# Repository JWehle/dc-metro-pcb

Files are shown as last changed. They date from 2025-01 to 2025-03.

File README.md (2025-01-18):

This repository holds the files used to design and manufacture the DCTransistor boards themselves.

[DCTransistor_updated.svg](DCTransistor_updated.svg) is an InkScape project file containing the PCB artwork (i.e. map design). The map is the inkscape file used on the most recent (Bidirectional) version of the boards.

The original Inkscape file used to create the first production DCTransistor board run is still available at [DCTransistor_orig.svg](DCTransistor_orig.svg)

`DCTransistor_*_BOM.xlsx` files are bills of materials needed to specify the board parts when ordering from JLCPCB.

The remaining files in `DCTransistor_*_Kicad_Modules.zip` are modified Kicad modules with modified PCB footprints from the default parts' Kicad libraries. Specifically, the footprints were modified to remove nearly all material that would normally be printed on a PCB and shrunk the silkscreen used to identify the orientation / polarity of the LEDs so that they would only be printed under the placed LEDs. 

The best way to get started modifying the projectin KiCad is to download all the Kicad files for a project (everything except the .svg) into a single folder, with the Kicad_Modules zip extracted as a sub-folder, and load the folder as a new KiCad project. The Kicad_Modules extracted sub-folder will need to be added to Kicad as a new source of footprints to use with the project.

Turning DCTransistor.svg into a KiCad modules requires using the [svg2shenzhen module](https://github.com/badgeek/svg2shenzhen). This [DEFCON talk from TwinkleTwinkie](https://www.youtube.com/watch?v=Sbkvza8cKQE) was my starting point learning how to make PCB art and turn it into a functioning board.

All contents of this folder are [licensed](LICENSE.md) under a Creative Commons Attribution-NonCommercial-ShareAlike 4.0 International Public License.

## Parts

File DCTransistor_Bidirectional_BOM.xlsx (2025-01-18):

Comment | Designator | Footprint | LCSC Part Number | Basic? | Doable |  | Old Part Numbers
MMBT3904 | Q1,Q0 | SOT-23 | C20526 | Y | Y |  | C20526
1N5819WS | D0 | SOD-323 | C191023 | Y | Y |  | C191023
SN74LVC1T45DBV | U3 | SOT-23-6 | C7843 | Y | Y |  | C7843
CH340C | U0 | SOIC-16_3.9x9.9mm_P1.27mm | C84681 | N | N |  | C84681
ESP-12F | U2 | ESP-12E | C82891 | N | N |  | C82891
AMS1117-3.3 | U1 | SOT-223-3_TabPin2 | C6186 | Y | Y |  | C351784
SW_SPST | SW0 | SW_DIP_SPSTx01_Slide_6.7x4.1mm_W6.73mm_P2.54mm_LowProfile_JPin | C54948 | N | N |  | C54948
300 | R8 | R_0402_1005Metric | C25102 | Y | Y |  | C138010
12k | R4,R5 | R_0402_1005Metric | C25752 | Y | Y |  | C144798
470 | R1,R2 | R_0402_1005Metric | C25117 | Y | Y | 0402 | C114433
10k | R6,R7,R9 | R_0402_1005Metric | C25744 | Y | Y | 0402 | C17414
5.1kR | R3,R0 | R_0402_1005Metric | C25905 | Y | Y | 0402 | C14677
USB_C_Receptacle | J0 | USB_C_Receptacle_HRO_TYPE-C-31-M-12 | C165948 | N | N |  | C165948
WS2812B_2.0mm_2.0mm | D2,D3,D4,D5,D6,D7,D8,D9,D10,D11,D12,D13,D14,D15,D16,D17,D18,D19,D20,D21,D22,D23,D24,D25,D26,D27,D28,D29,D30,D31,D32,D33,D34,D35,D36,D37,D38,D39,D40,D41,D42,D43,D44,D45,D46,D47,D48,D49,D50,D51,D52,D53,D54,D55,D56,D57,D58,D59,D60,D61,D62,D63,D64,D65,D66,D67,D68,D69,D70,D71,D72,D73,D74,D75,D76,D77,D78,D79,D80,D81,D82,D83,D84,D85,D86,D87,D88,D89,D90,D91,D92,D93,D94,D95,D96,D97,D98,D99,D100,D101,D102,D103,D104,D105,D106,D107,D108,D109,D110,D111,D112,D113,D114,D115,D116,D117,D118,D119,D120,D121,D122,D123,D124,D125,D126,D127,D128,D129,D130,D131,D132,D133,D134,D135,D136,D137,D138,D139,D140,D141,D142,D143,D144,D145,D146,D147,D148,D149,D150,D151,D152,D153,D154,D155,D156,D157,D158,D159,D160,D161,D162,D163,D164,D165,D166,D167,D168,D169,D170,D171,D172,D173,D174,D175,D176,D177,D178,D179,D180,D181,D182,D183,D184,D185,D186,D187,D188,D189,D190,D191,D192,D193,D194,D195,D196,D197,D198,D199,D200,D201,D202,D203,D204,D205,D206,D207,D208 | LED_2020 | C5349955 | N | N | To allow economic assembly | C2761795
100nf | C0,C2 | C_0603_1608Metric | C14663 | Y | Y | 0603 | C88219
10uF | C1,C3,C4,C5,C6,C7,C8,C9,C10,C11,C12,C13,C14,C15,C16,C17,C18,C19,C20,C21,C22,C23,C24,C25,C26,C27,C28,C29,C30,C31,C32,C33,C34,C35,C36,C37,C38,C39,C40,C41,C42,C43 | C_0402_1005Metric | C15525 | Y | Y | 0402 | C466780

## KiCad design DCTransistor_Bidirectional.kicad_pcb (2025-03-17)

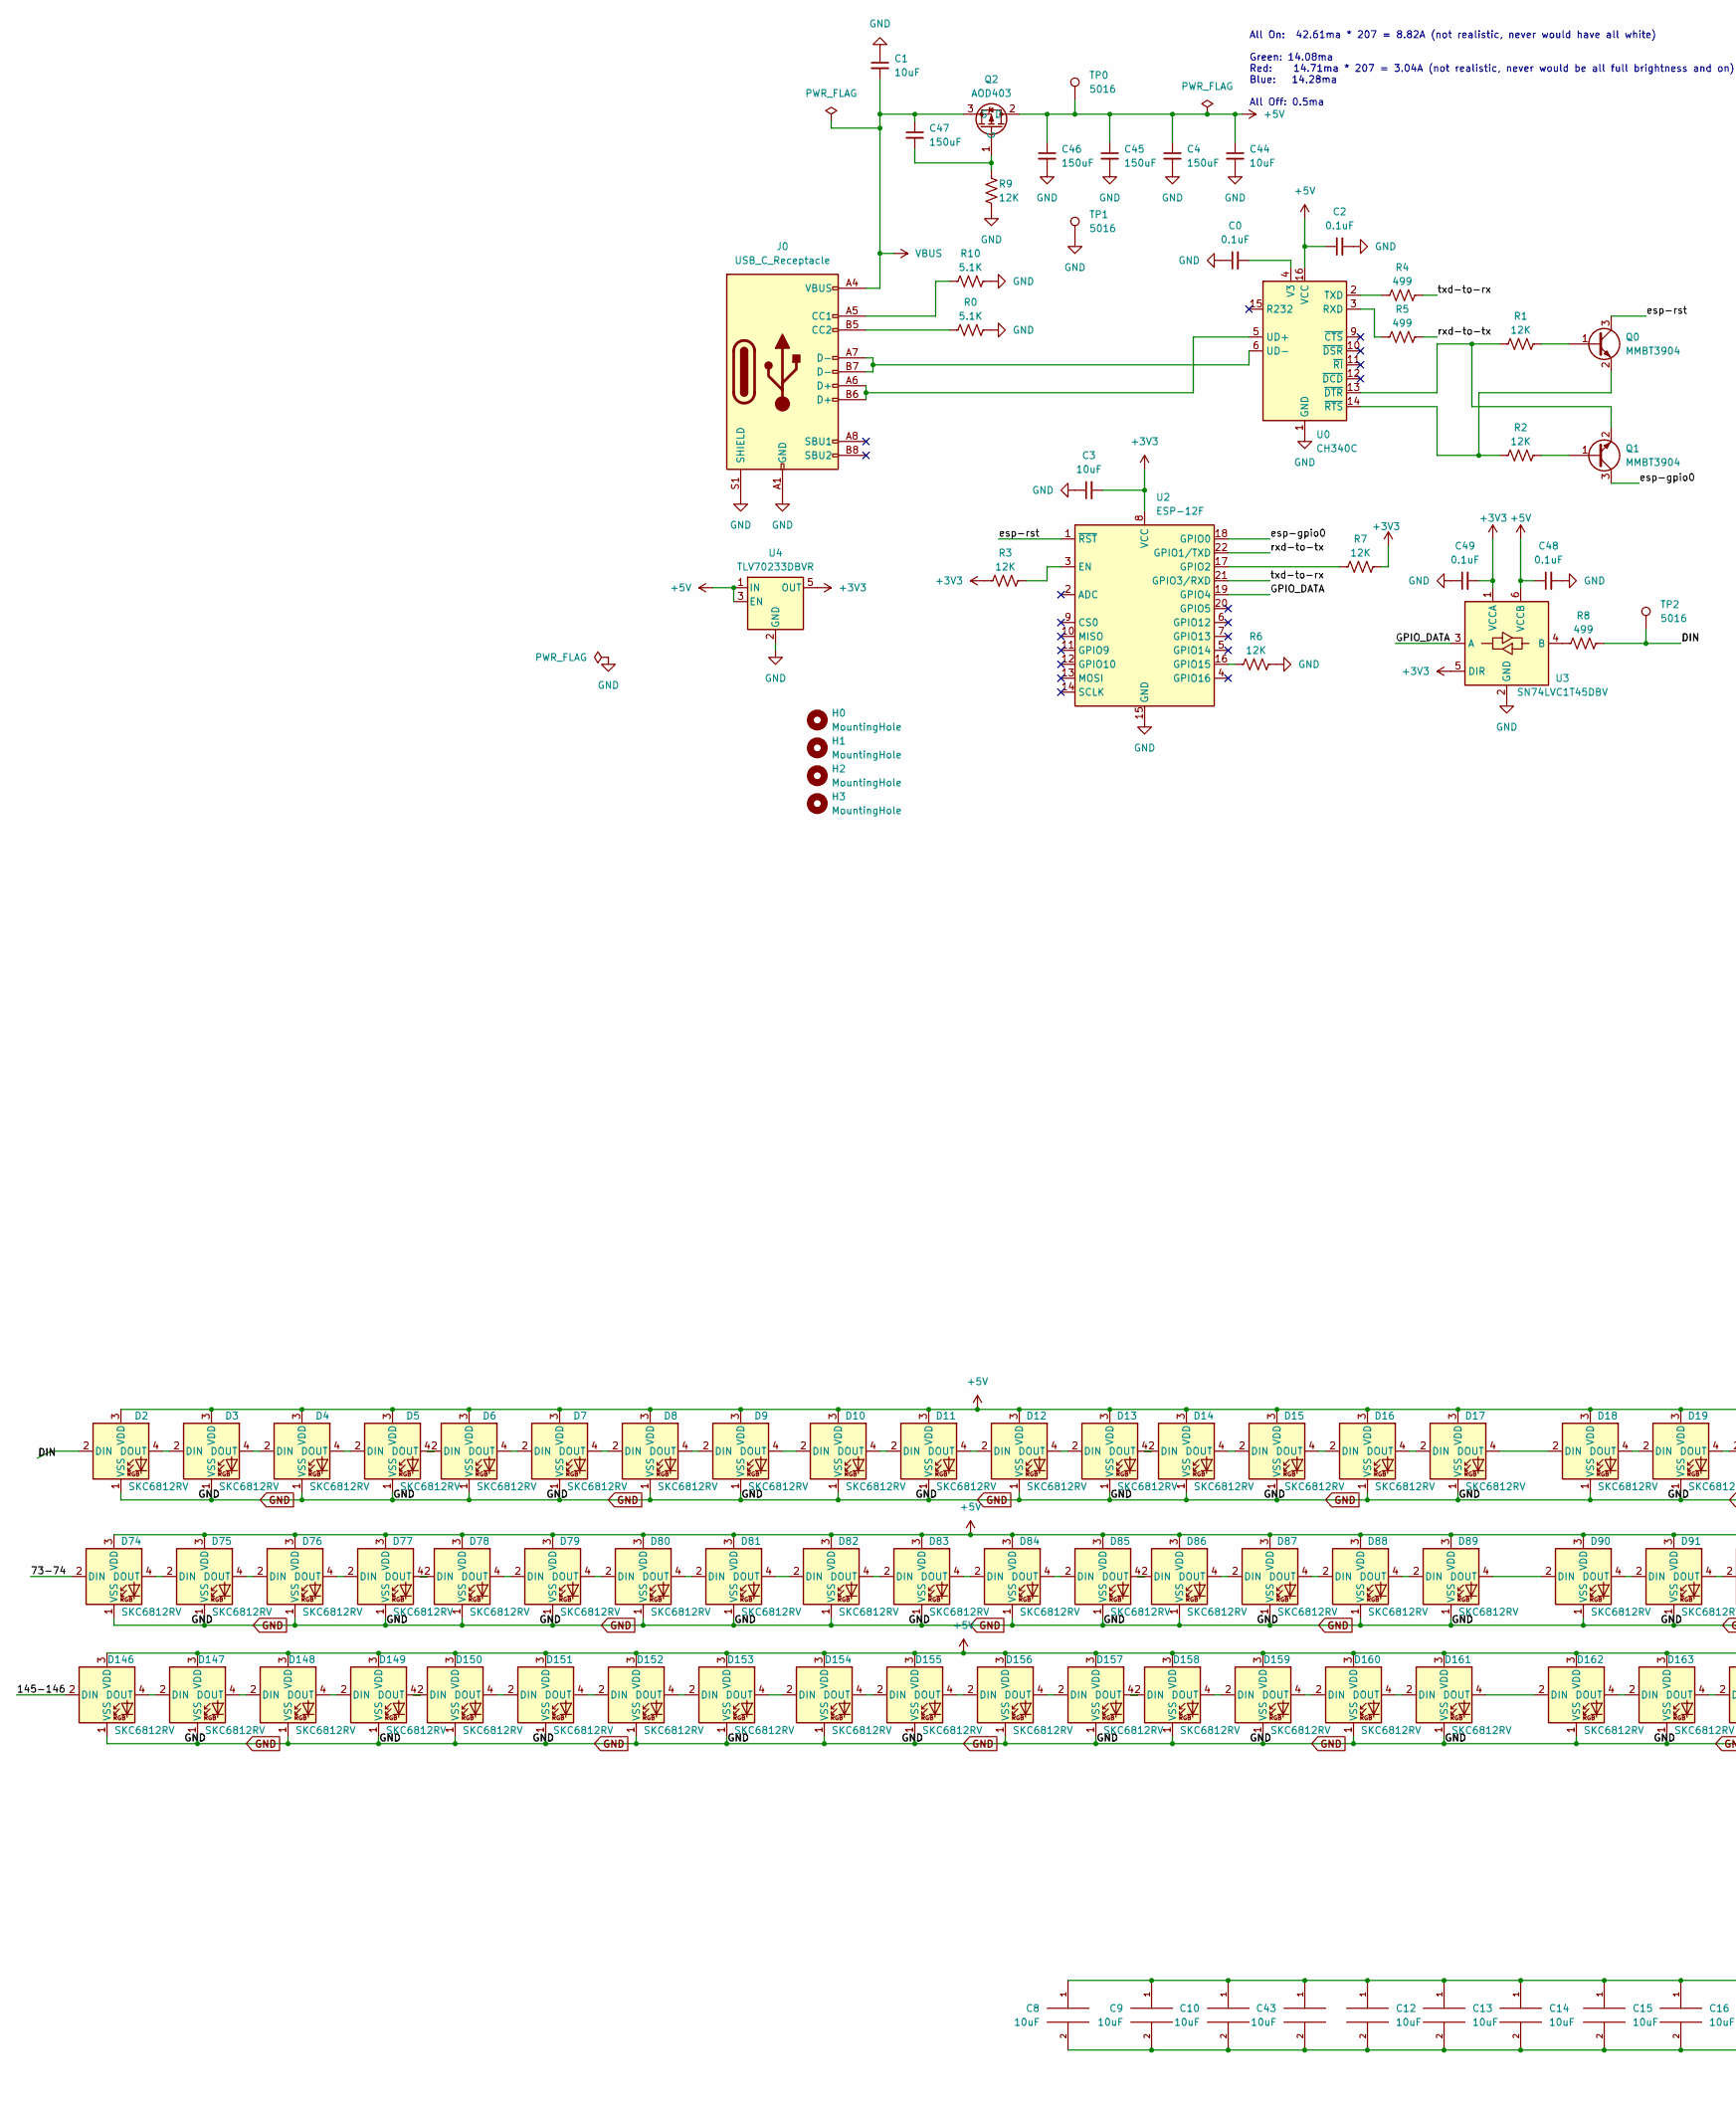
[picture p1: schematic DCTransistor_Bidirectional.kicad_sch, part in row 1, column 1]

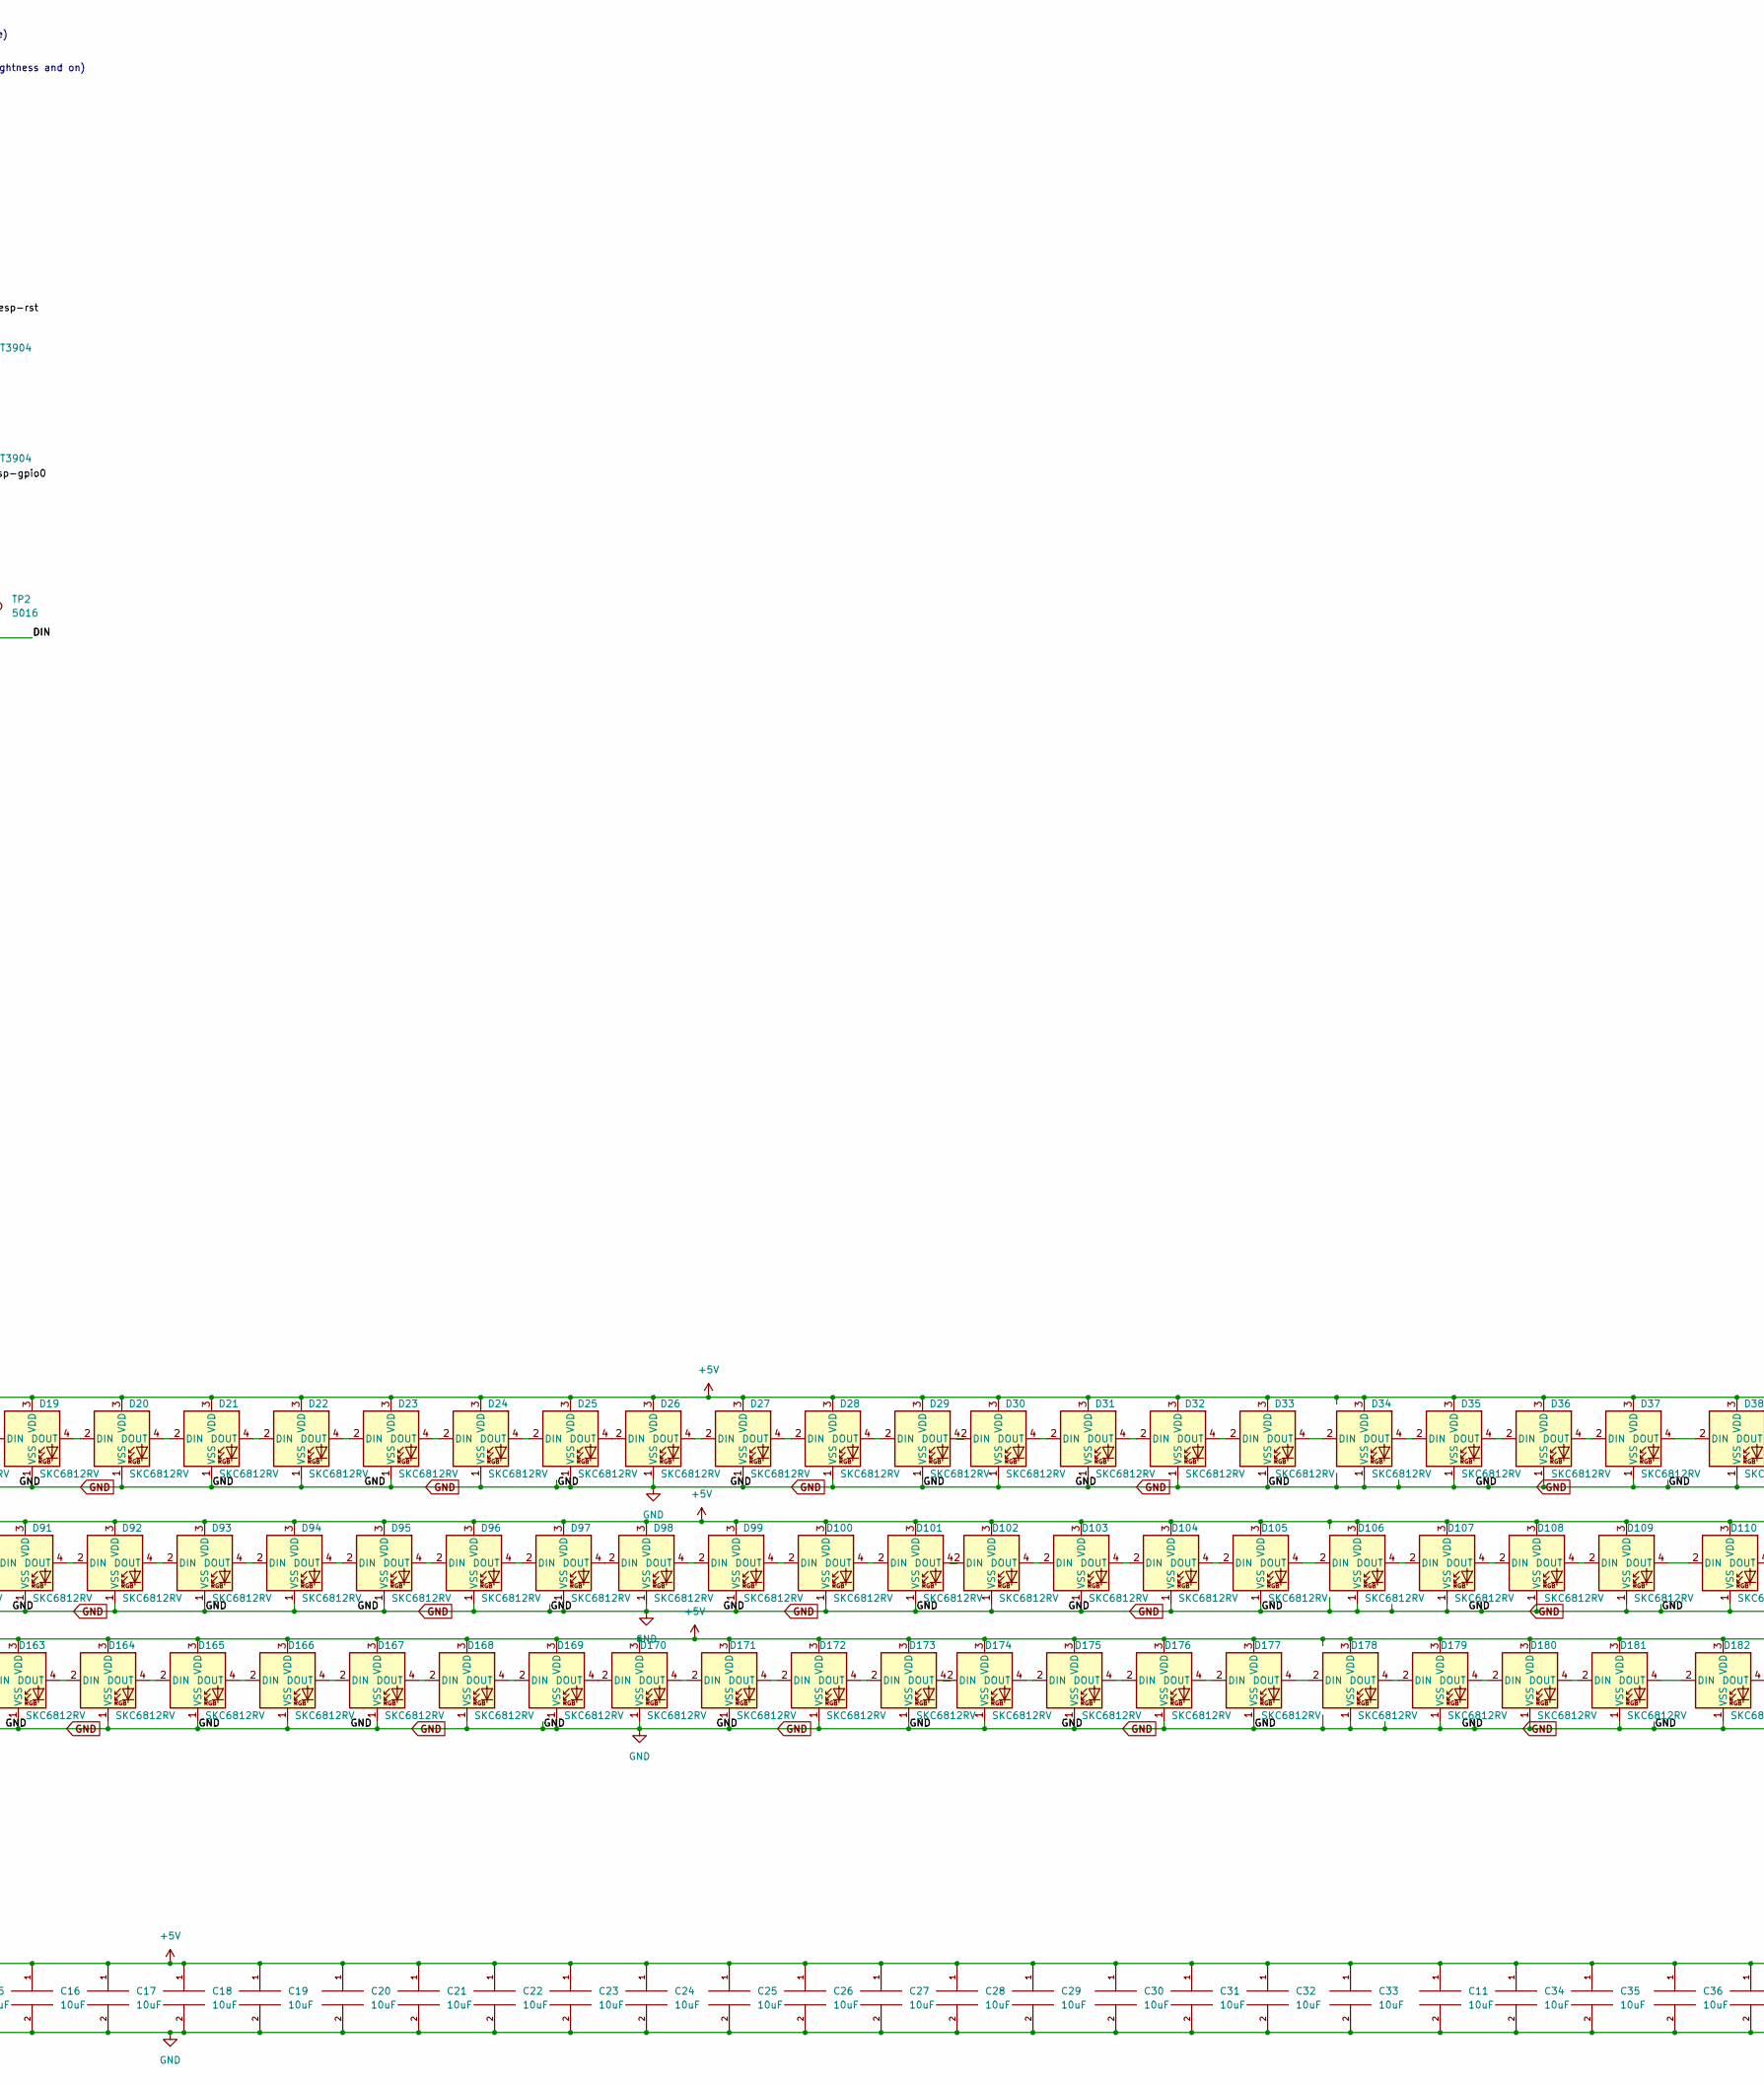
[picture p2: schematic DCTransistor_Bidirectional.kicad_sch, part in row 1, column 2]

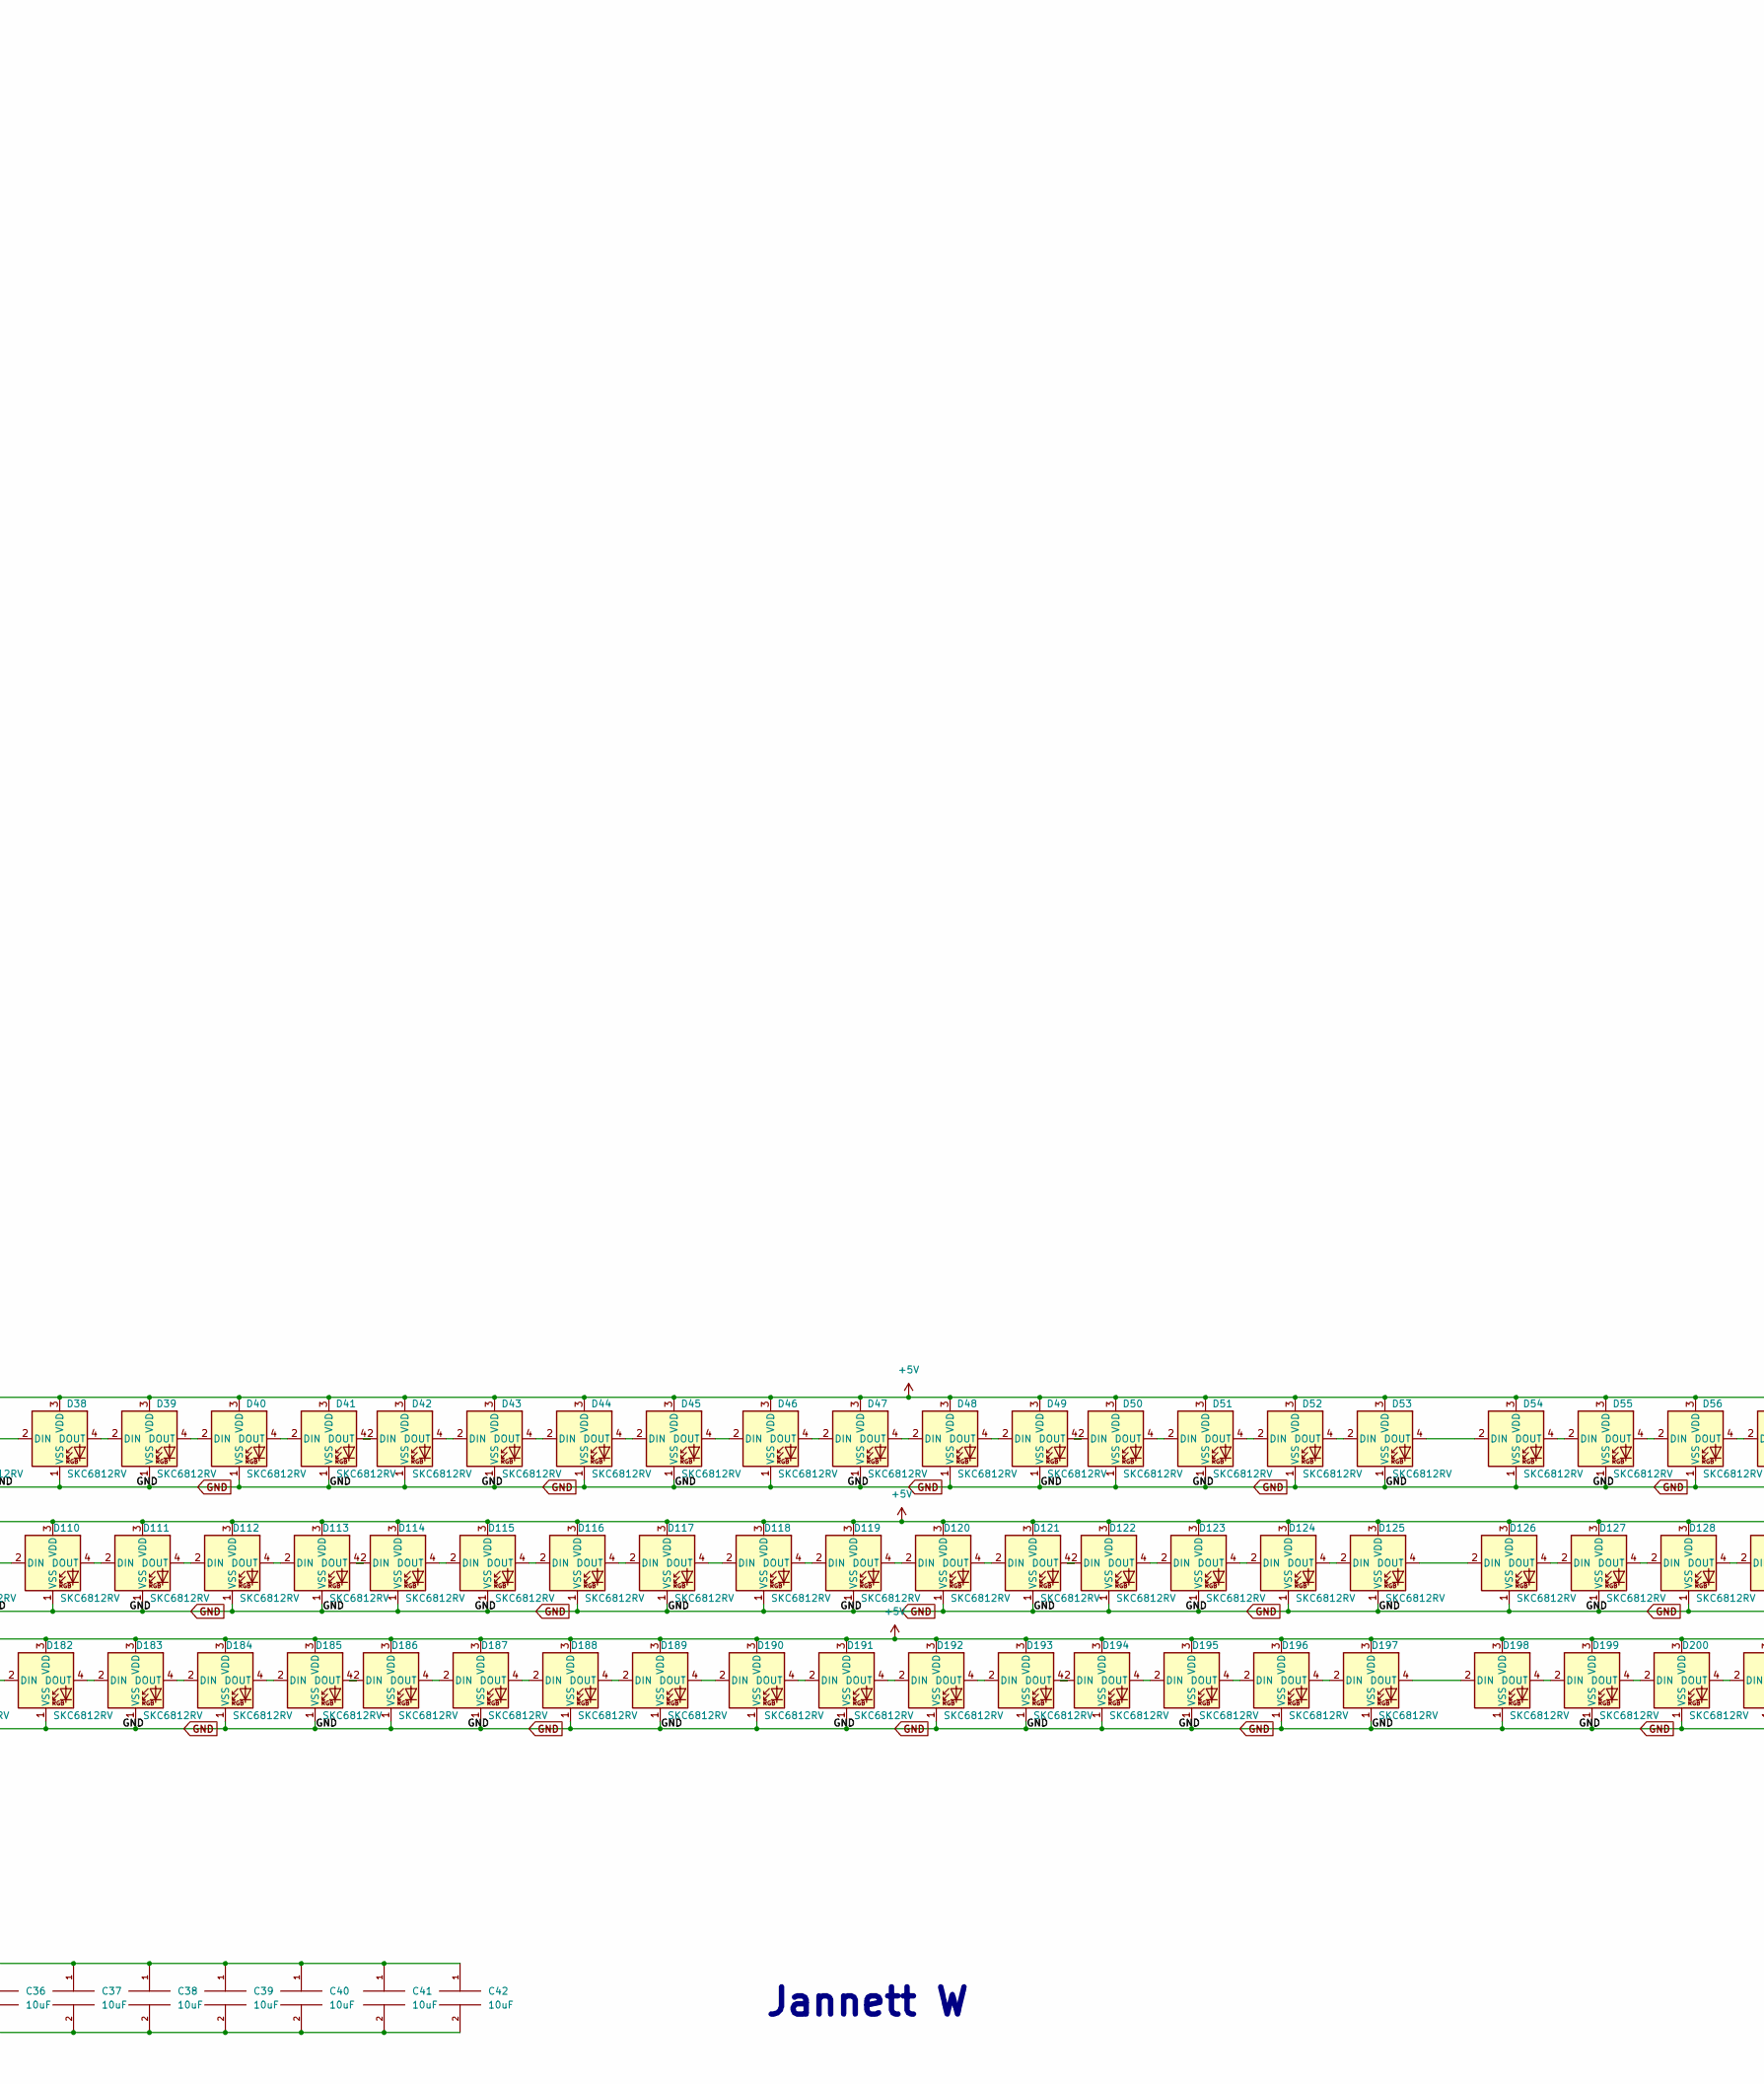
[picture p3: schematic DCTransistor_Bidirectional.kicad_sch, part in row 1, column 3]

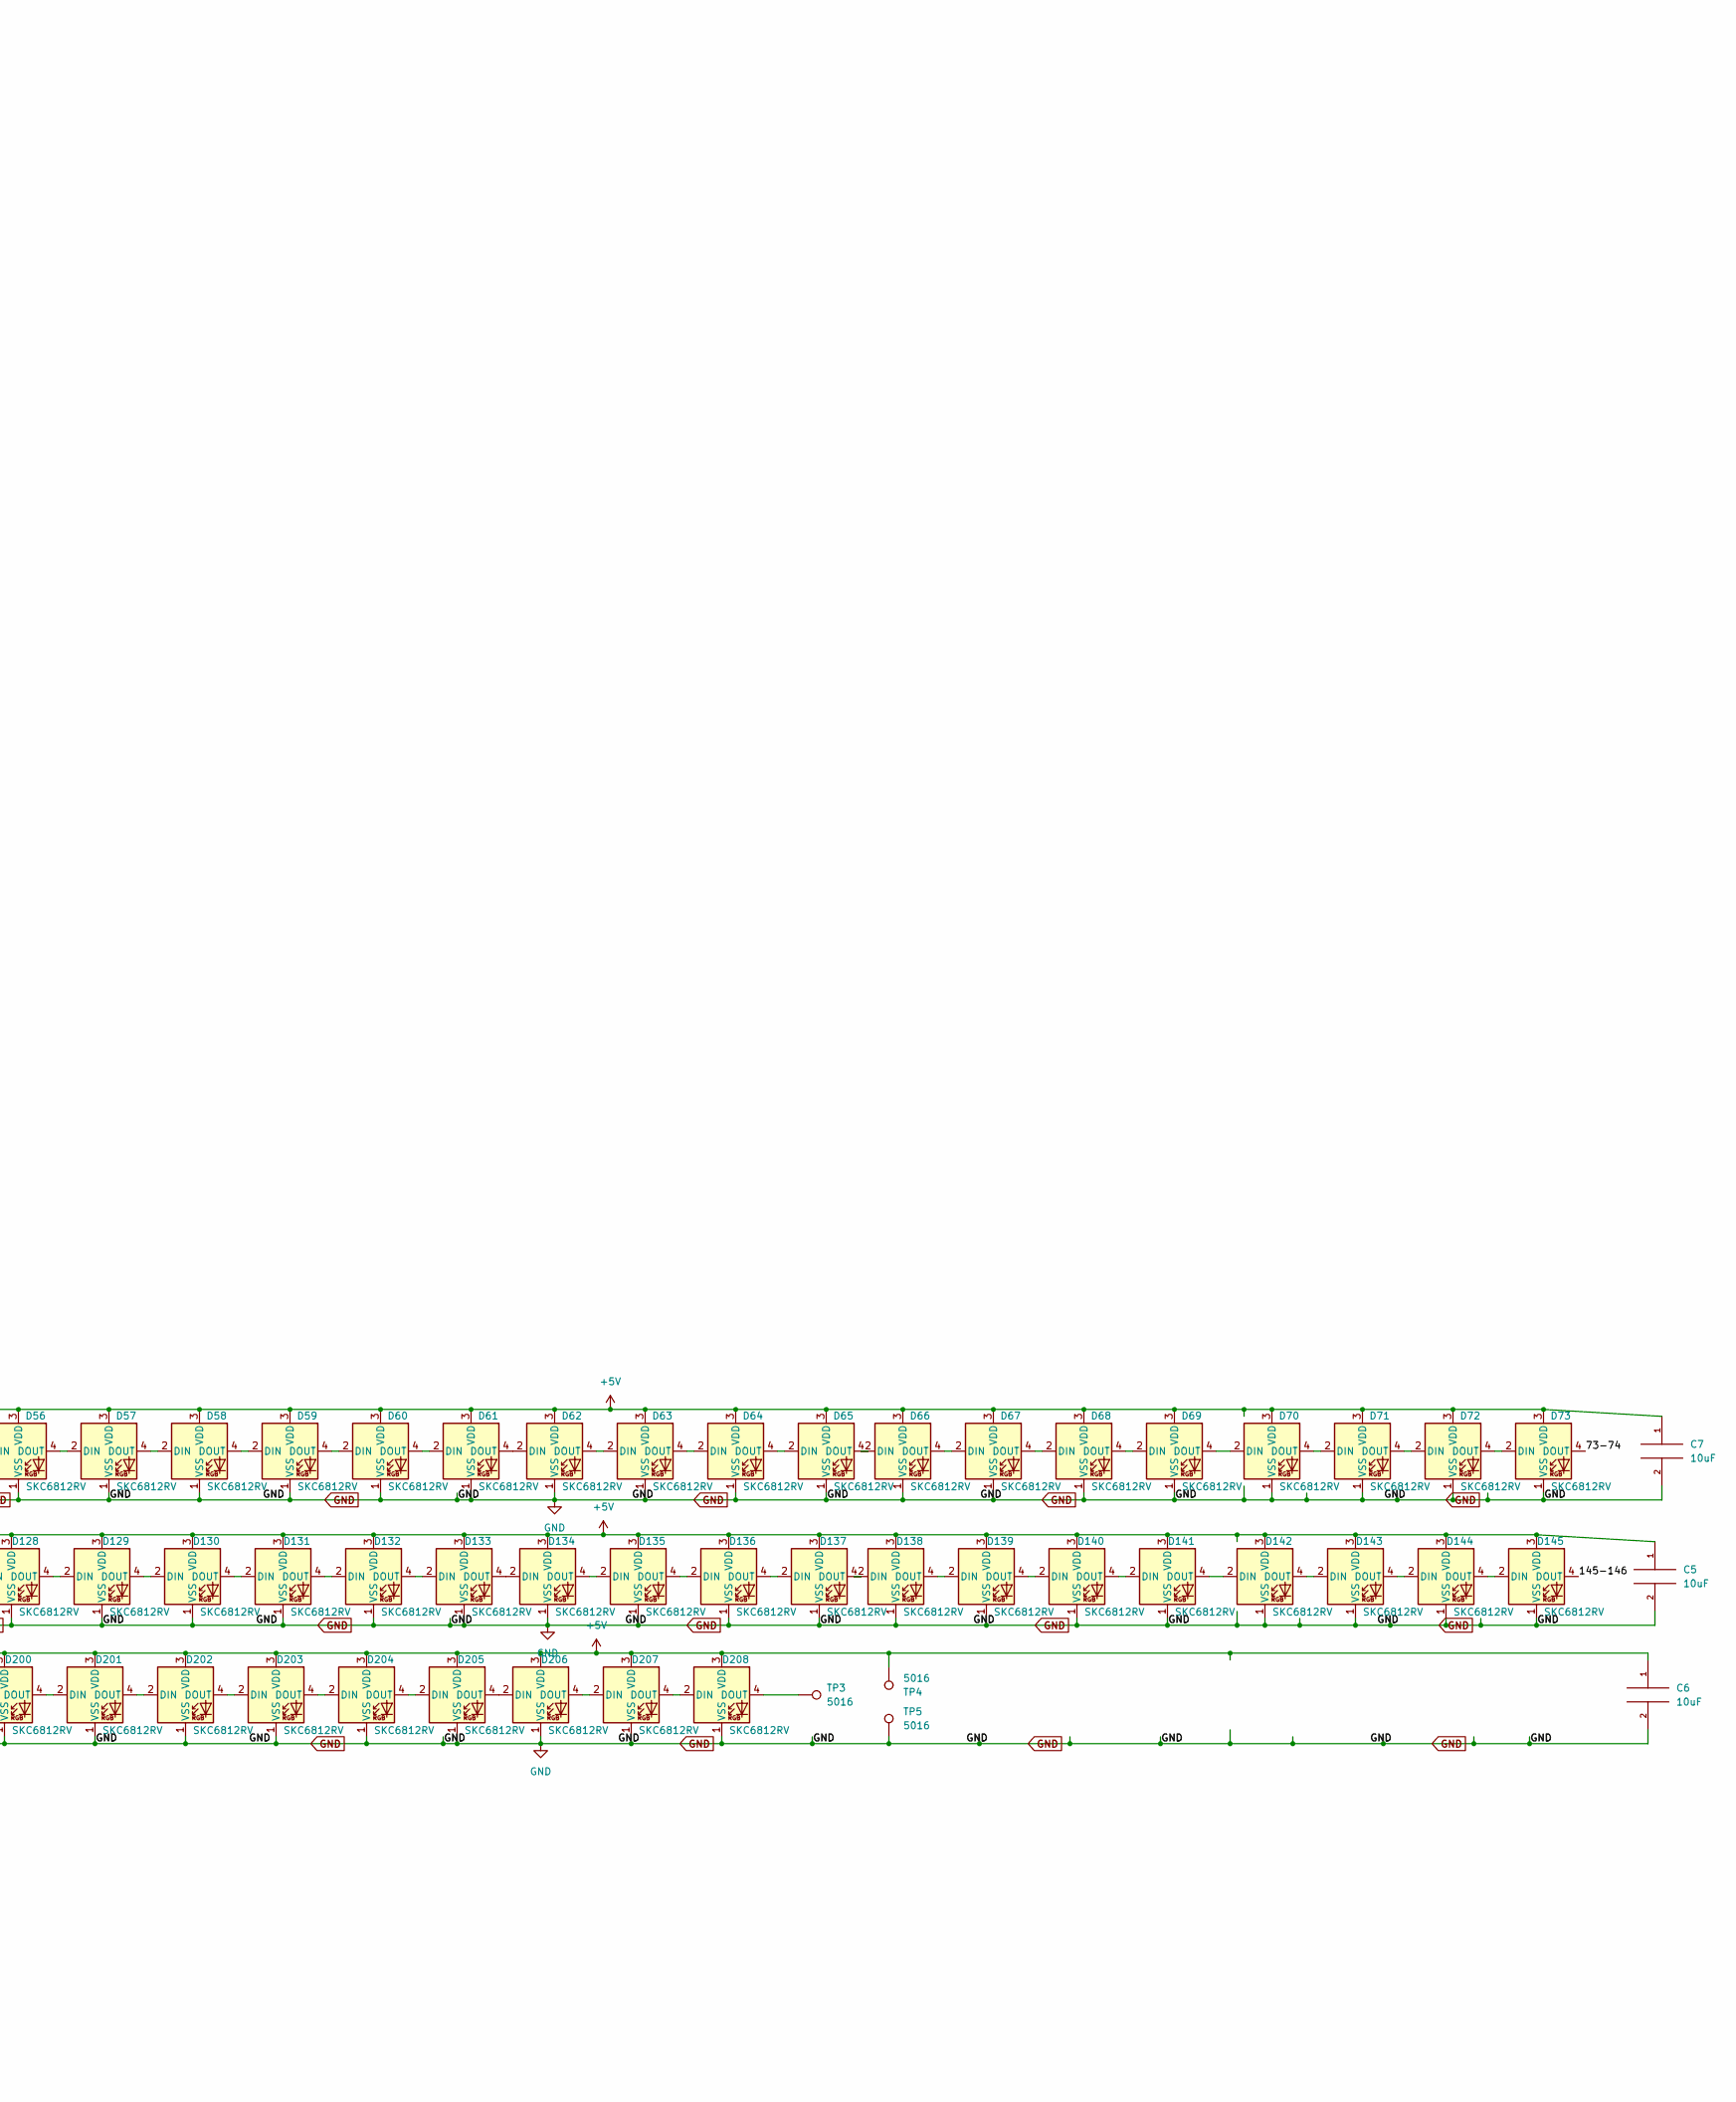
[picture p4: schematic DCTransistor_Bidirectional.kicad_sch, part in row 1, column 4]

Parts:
C0, C2, C48, C49: 0.1uF; C_0603_1608Metric
C1, C3, C5, C6, C7, C8, C9, C10, C11, C12, C13, C14, C15, C16, C17, C18, C19, C20, C21, C22, C23, C24, C25, C26, C27, C28, C29, C30, C31, C32, C33, C34, C35, C36, C37, C38, C39, C40, C41, C42, C43, C44: 10uF; C_0603_1608Metric
C4, C45, C46, C47: 150uF; CP_EIA-7343-43_Kemet-X_Pad2.25x2.55mm_HandSolder
D2, D3, D4, D5, D6, D7, D8, D9, D10, D11, D12, D13, D14, D15, D16, D17, D18, D19, D20, D21, D22, D23, D24, D25, D26, D27, D28, D29, D30, D31, D32, D33, D34, D35, D36, D37, D38, D39, D40, D41, D42, D43, D44, D45, D46, D47, D48, D49, D50, D51, D52, D53, D54, D55, D56, D57, D58, D59, D60, D61, D62, D63, D64, D65, D66, D67, D68, D69, D70, D71, D72, D73, D74, D75, D76, D77, D78, D79, D80, D81, D82, D83, D84, D85, D86, D87, D88, D89, D90, D91, D92, D93, D94, D95, D96, D97, D98, D99, D100, D101, D102, D103, D104, D105, D106, D107, D108, D109, D110, D111, D112, D113, D114, D115, D116, D117, D118, D119, D120, D121, D122, D123, D124, D125, D126, D127, D128, D129, D130, D131, D132, D133, D134, D135, D136, D137, D138, D139, D140, D141, D142, D143, D144, D145, D146, D147, D148, D149, D150, D151, D152, D153, D154, D155, D156, D157, D158, D159, D160, D161, D162, D163, D164, D165, D166, D167, D168, D169, D170, D171, D172, D173, D174, D175, D176, D177, D178, D179, D180, D181, D182, D183, D184, D185, D186, D187, D188, D189, D190, D191, D192, D193, D194, D195, D196, D197, D198, D199, D200, D201, D202, D203, D204, D205, D206, D207, D208: SKC6812RV; LED_SK6812_PLCC4_5.0x5.0mm_P3.2mm_no_silk
H0, H1, H2, H3: MountingHole; MountingHole_6.4mm_M6
J0: USB_C_Receptacle; USB_C_Receptacle_GSB1C4621DS2HR
Q0, Q1: MMBT3904; SOT-23-3
Q2: AOD403; TO-252-2
R0, R10: 5.1K; R_0603_1608Metric
R1, R2, R3, R6, R7, R9: 12K; R_0603_1608Metric
R4, R5, R8: 499; R_0603_1608Metric
TP0, TP1, TP2, TP3, TP4, TP5: 5016; TestPoint_Keystone_5016_Compact
U0: CH340C; SOIC-16_3.9x9.9mm_P1.27mm
U2: ESP-12F; ESP-12E
U3: SN74LVC1T45DBV; SOT-23-6_Handsoldering
U4: TLV70233DBVR; SOT-23-5

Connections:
+3V3: C3.2, C49.2, R3.1, R7.2, U2.8 (VCC), U3.1 (VCCA), U3.5 (DIR), U4.5 (OUT)
+5V: C2.1, C4.1, C5.1, C6.1, C7.1, C8.1, C9.1, C10.1, C11.1, C12.1, C13.1, C14.1, C15.1, C16.1, C17.1, C18.1, C19.1, C20.1, C21.1, C22.1, C23.1, C24.1, C25.1, C26.1, C27.1, C28.1, C29.1, C30.1, C31.1, C32.1, C33.1, C34.1, C35.1, C36.1, C37.1, C38.1, C39.1, C40.1, C41.1, C42.1, C43.1, C44.1, C45.1, C46.1, C48.1, D2.3 (VDD), D3.3 (VDD), D4.3 (VDD), D5.3 (VDD), D6.3 (VDD), D7.3 (VDD), D8.3 (VDD), D9.3 (VDD), D10.3 (VDD), D11.3 (VDD), D12.3 (VDD), D13.3 (VDD), D14.3 (VDD), D15.3 (VDD), D16.3 (VDD), D17.3 (VDD), D18.3 (VDD), D19.3 (VDD), D20.3 (VDD), D21.3 (VDD), D22.3 (VDD), D23.3 (VDD), D24.3 (VDD), D25.3 (VDD), D26.3 (VDD), D27.3 (VDD), D28.3 (VDD), D29.3 (VDD), D30.3 (VDD), D31.3 (VDD), D32.3 (VDD), D33.3 (VDD), D34.3 (VDD), D35.3 (VDD), D36.3 (VDD), D37.3 (VDD), D38.3 (VDD), D39.3 (VDD), D40.3 (VDD), D41.3 (VDD), D42.3 (VDD), D43.3 (VDD), D44.3 (VDD), D45.3 (VDD), D46.3 (VDD), D47.3 (VDD), D48.3 (VDD), D49.3 (VDD), D50.3 (VDD), D51.3 (VDD), D52.3 (VDD), D53.3 (VDD), D54.3 (VDD), D55.3 (VDD), D56.3 (VDD), D57.3 (VDD), D58.3 (VDD), D59.3 (VDD), D60.3 (VDD), D61.3 (VDD)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
/73-74: D73.4 (DOUT), D74.2 (DIN)
/145-146: D145.4 (DOUT), D146.2 (DIN)
/DIN: D2.2 (DIN), R8.2, TP2.1
/GPIO_DATA: U2.19 (GPIO4), U3.3 (A)
/esp-gpio0: Q1.3 (C), U2.18 (GPIO0)
/esp-rst: Q0.3 (C), U2.1 (~RST)
/rxd-to-tx: R5.2, U2.22 (GPIO1/TXD)
/txd-to-rx: R4.2, U2.21 (GPIO3/RXD)
GND: C0.1, C1.1, C2.2, C3.1, C4.2, C5.2, C6.2, C7.2, C8.2, C9.2, C10.2, C11.2, C12.2, C13.2, C14.2, C15.2, C16.2, C17.2, C18.2, C19.2, C20.2, C21.2, C22.2, C23.2, C24.2, C25.2, C26.2, C27.2, C28.2, C29.2, C30.2, C31.2, C32.2, C33.2, C34.2, C35.2, C36.2, C37.2, C38.2, C39.2, C40.2, C41.2, C42.2, C43.2, C44.2, C45.2, C46.2, C48.2, C49.1, D2.1 (VSS), D3.1 (VSS), D4.1 (VSS), D5.1 (VSS), D6.1 (VSS), D7.1 (VSS), D8.1 (VSS), D9.1 (VSS), D10.1 (VSS), D11.1 (VSS), D12.1 (VSS), D13.1 (VSS), D14.1 (VSS), D15.1 (VSS), D16.1 (VSS), D17.1 (VSS), D18.1 (VSS), D19.1 (VSS), D20.1 (VSS), D21.1 (VSS), D22.1 (VSS), D23.1 (VSS), D24.1 (VSS), D25.1 (VSS), D26.1 (VSS), D27.1 (VSS), D28.1 (VSS), D29.1 (VSS), D30.1 (VSS), D31.1 (VSS), D32.1 (VSS), D33.1 (VSS), D34.1 (VSS), D35.1 (VSS), D36.1 (VSS), D37.1 (VSS), D38.1 (VSS), D39.1 (VSS), D40.1 (VSS), D41.1 (VSS), D42.1 (VSS), D43.1 (VSS), D44.1 (VSS), D45.1 (VSS), D46.1 (VSS), D47.1 (VSS), D48.1 (VSS), D49.1 (VSS), D50.1 (VSS), D51.1 (VSS), D52.1 (VSS), D53.1 (VSS), D54.1 (VSS), D55.1 (VSS), D56.1 (VSS), D57.1 (VSS)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
unnamed: D2.4 (DOUT), D3.2 (DIN)
unnamed: D3.4 (DOUT), D4.2 (DIN)
unnamed: D4.4 (DOUT), D5.2 (DIN)
unnamed: D5.4 (DOUT), D6.2 (DIN)
unnamed: D6.4 (DOUT), D7.2 (DIN)
unnamed: D7.4 (DOUT), D8.2 (DIN)
unnamed: D8.4 (DOUT), D9.2 (DIN)
unnamed: D9.4 (DOUT), D10.2 (DIN)
unnamed: D10.4 (DOUT), D11.2 (DIN)
unnamed: D11.4 (DOUT), D12.2 (DIN)
unnamed: D12.4 (DOUT), D13.2 (DIN)
unnamed: D13.4 (DOUT), D14.2 (DIN)
unnamed: D14.4 (DOUT), D15.2 (DIN)
unnamed: D15.4 (DOUT), D16.2 (DIN)
unnamed: D16.4 (DOUT), D17.2 (DIN)
unnamed: D17.4 (DOUT), D18.2 (DIN)
unnamed: D18.4 (DOUT), D19.2 (DIN)
unnamed: D19.4 (DOUT), D20.2 (DIN)
unnamed: D20.4 (DOUT), D21.2 (DIN)
unnamed: D21.4 (DOUT), D22.2 (DIN)
unnamed: D22.4 (DOUT), D23.2 (DIN)
unnamed: D23.4 (DOUT), D24.2 (DIN)
unnamed: D24.4 (DOUT), D25.2 (DIN)
unnamed: D25.4 (DOUT), D26.2 (DIN)
unnamed: D26.4 (DOUT), D27.2 (DIN)
unnamed: D27.4 (DOUT), D28.2 (DIN)
unnamed: D28.4 (DOUT), D29.2 (DIN)
unnamed: D29.4 (DOUT), D30.2 (DIN)
unnamed: D30.4 (DOUT), D31.2 (DIN)
unnamed: D31.4 (DOUT), D32.2 (DIN)
unnamed: D32.4 (DOUT), D33.2 (DIN)
unnamed: D33.4 (DOUT), D34.2 (DIN)
unnamed: D34.4 (DOUT), D35.2 (DIN)
unnamed: D35.4 (DOUT), D36.2 (DIN)
unnamed: D36.4 (DOUT), D37.2 (DIN)
unnamed: D37.4 (DOUT), D38.2 (DIN)
unnamed: D38.4 (DOUT), D39.2 (DIN)
unnamed: D39.4 (DOUT), D40.2 (DIN)
unnamed: D40.4 (DOUT), D41.2 (DIN)
unnamed: D41.4 (DOUT), D42.2 (DIN)
unnamed: D42.4 (DOUT), D43.2 (DIN)
unnamed: D43.4 (DOUT), D44.2 (DIN)
unnamed: D44.4 (DOUT), D45.2 (DIN)
unnamed: D45.4 (DOUT), D46.2 (DIN)
unnamed: D46.4 (DOUT), D47.2 (DIN)
unnamed: D47.4 (DOUT), D48.2 (DIN)
unnamed: D48.4 (DOUT), D49.2 (DIN)
unnamed: D49.4 (DOUT), D50.2 (DIN)
unnamed: D50.4 (DOUT), D51.2 (DIN)
unnamed: D51.4 (DOUT), D52.2 (DIN)
unnamed: D52.4 (DOUT), D53.2 (DIN)
unnamed: D53.4 (DOUT), D54.2 (DIN)
unnamed: D54.4 (DOUT), D55.2 (DIN)
unnamed: D55.4 (DOUT), D56.2 (DIN)
unnamed: D56.4 (DOUT), D57.2 (DIN)
unnamed: D57.4 (DOUT), D58.2 (DIN)
unnamed: D58.4 (DOUT), D59.2 (DIN)
unnamed: D59.4 (DOUT), D60.2 (DIN)
unnamed: D60.4 (DOUT), D61.2 (DIN)
unnamed: D61.4 (DOUT), D62.2 (DIN)
unnamed: D62.4 (DOUT), D63.2 (DIN)
unnamed: D63.4 (DOUT), D64.2 (DIN)
unnamed: D64.4 (DOUT), D65.2 (DIN)
unnamed: D65.4 (DOUT), D66.2 (DIN)
unnamed: D66.4 (DOUT), D67.2 (DIN)
unnamed: D67.4 (DOUT), D68.2 (DIN)
unnamed: D68.4 (DOUT), D69.2 (DIN)
unnamed: D69.4 (DOUT), D70.2 (DIN)
unnamed: D70.4 (DOUT), D71.2 (DIN)
unnamed: D71.4 (DOUT), D72.2 (DIN)
unnamed: D72.4 (DOUT), D73.2 (DIN)
unnamed: D74.4 (DOUT), D75.2 (DIN)
unnamed: D75.4 (DOUT), D76.2 (DIN)
unnamed: D76.4 (DOUT), D77.2 (DIN)
unnamed: D77.4 (DOUT), D78.2 (DIN)
unnamed: D78.4 (DOUT), D79.2 (DIN)
unnamed: D79.4 (DOUT), D80.2 (DIN)
unnamed: D80.4 (DOUT), D81.2 (DIN)
unnamed: D81.4 (DOUT), D82.2 (DIN)
unnamed: D82.4 (DOUT), D83.2 (DIN)
unnamed: D83.4 (DOUT), D84.2 (DIN)
unnamed: D84.4 (DOUT), D85.2 (DIN)
unnamed: D85.4 (DOUT), D86.2 (DIN)
unnamed: D86.4 (DOUT), D87.2 (DIN)
unnamed: D87.4 (DOUT), D88.2 (DIN)
unnamed: D88.4 (DOUT), D89.2 (DIN)
unnamed: D89.4 (DOUT), D90.2 (DIN)
unnamed: D90.4 (DOUT), D91.2 (DIN)
unnamed: D91.4 (DOUT), D92.2 (DIN)
unnamed: D92.4 (DOUT), D93.2 (DIN)
unnamed: D93.4 (DOUT), D94.2 (DIN)
unnamed: D94.4 (DOUT), D95.2 (DIN)
unnamed: D95.4 (DOUT), D96.2 (DIN)
unnamed: D96.4 (DOUT), D97.2 (DIN)
unnamed: D97.4 (DOUT), D98.2 (DIN)
unnamed: D98.4 (DOUT), D99.2 (DIN)
unnamed: D99.4 (DOUT), D100.2 (DIN)
unnamed: D100.4 (DOUT), D101.2 (DIN)
unnamed: D101.4 (DOUT), D102.2 (DIN)
unnamed: D102.4 (DOUT), D103.2 (DIN)
unnamed: D103.4 (DOUT), D104.2 (DIN)
unnamed: D104.4 (DOUT), D105.2 (DIN)
unnamed: D105.4 (DOUT), D106.2 (DIN)
unnamed: D106.4 (DOUT), D107.2 (DIN)
unnamed: D107.4 (DOUT), D108.2 (DIN)
unnamed: D108.4 (DOUT), D109.2 (DIN)
unnamed: D109.4 (DOUT), D110.2 (DIN)
unnamed: D110.4 (DOUT), D111.2 (DIN)
unnamed: D111.4 (DOUT), D112.2 (DIN)
unnamed: D112.4 (DOUT), D113.2 (DIN)
unnamed: D113.4 (DOUT), D114.2 (DIN)
unnamed: D114.4 (DOUT), D115.2 (DIN)
unnamed: D115.4 (DOUT), D116.2 (DIN)
unnamed: D116.4 (DOUT), D117.2 (DIN)
unnamed: D117.4 (DOUT), D118.2 (DIN)
unnamed: D118.4 (DOUT), D119.2 (DIN)
unnamed: D119.4 (DOUT), D120.2 (DIN)
unnamed: D120.4 (DOUT), D121.2 (DIN)
unnamed: D121.4 (DOUT), D122.2 (DIN)
unnamed: D122.4 (DOUT), D123.2 (DIN)
unnamed: D123.4 (DOUT), D124.2 (DIN)
unnamed: D124.4 (DOUT), D125.2 (DIN)
unnamed: D125.4 (DOUT), D126.2 (DIN)
unnamed: D126.4 (DOUT), D127.2 (DIN)
unnamed: D127.4 (DOUT), D128.2 (DIN)
unnamed: D128.4 (DOUT), D129.2 (DIN)
unnamed: D129.4 (DOUT), D130.2 (DIN)
unnamed: D130.4 (DOUT), D131.2 (DIN)
unnamed: D131.4 (DOUT), D132.2 (DIN)
unnamed: D132.4 (DOUT), D133.2 (DIN)
unnamed: D133.4 (DOUT), D134.2 (DIN)
unnamed: D134.4 (DOUT), D135.2 (DIN)
unnamed: D135.4 (DOUT), D136.2 (DIN)
unnamed: D136.4 (DOUT), D137.2 (DIN)
unnamed: D137.4 (DOUT), D138.2 (DIN)
unnamed: D138.4 (DOUT), D139.2 (DIN)
unnamed: D139.4 (DOUT), D140.2 (DIN)
unnamed: D140.4 (DOUT), D141.2 (DIN)
unnamed: D141.4 (DOUT), D142.2 (DIN)
unnamed: D142.4 (DOUT), D143.2 (DIN)
unnamed: D143.4 (DOUT), D144.2 (DIN)
unnamed: D144.4 (DOUT), D145.2 (DIN)
unnamed: D146.4 (DOUT), D147.2 (DIN)
unnamed: D147.4 (DOUT), D148.2 (DIN)
unnamed: D148.4 (DOUT), D149.2 (DIN)
unnamed: D149.4 (DOUT), D150.2 (DIN)
unnamed: D150.4 (DOUT), D151.2 (DIN)
unnamed: D151.4 (DOUT), D152.2 (DIN)
unnamed: D152.4 (DOUT), D153.2 (DIN)
unnamed: D153.4 (DOUT), D154.2 (DIN)
unnamed: D154.4 (DOUT), D155.2 (DIN)
unnamed: D155.4 (DOUT), D156.2 (DIN)
unnamed: D156.4 (DOUT), D157.2 (DIN)
unnamed: D157.4 (DOUT), D158.2 (DIN)
unnamed: D158.4 (DOUT), D159.2 (DIN)
unnamed: D159.4 (DOUT), D160.2 (DIN)
unnamed: D160.4 (DOUT), D161.2 (DIN)
unnamed: D161.4 (DOUT), D162.2 (DIN)
unnamed: D162.4 (DOUT), D163.2 (DIN)
unnamed: D163.4 (DOUT), D164.2 (DIN)
unnamed: D164.4 (DOUT), D165.2 (DIN)
unnamed: D165.4 (DOUT), D166.2 (DIN)
unnamed: D166.4 (DOUT), D167.2 (DIN)
unnamed: D167.4 (DOUT), D168.2 (DIN)
unnamed: D168.4 (DOUT), D169.2 (DIN)
unnamed: D169.4 (DOUT), D170.2 (DIN)
unnamed: D170.4 (DOUT), D171.2 (DIN)
unnamed: D171.4 (DOUT), D172.2 (DIN)
unnamed: D172.4 (DOUT), D173.2 (DIN)
unnamed: D173.4 (DOUT), D174.2 (DIN)
unnamed: D174.4 (DOUT), D175.2 (DIN)
unnamed: D175.4 (DOUT), D176.2 (DIN)
unnamed: D176.4 (DOUT), D177.2 (DIN)
unnamed: D177.4 (DOUT), D178.2 (DIN)
unnamed: D178.4 (DOUT), D179.2 (DIN)
unnamed: D179.4 (DOUT), D180.2 (DIN)
unnamed: D180.4 (DOUT), D181.2 (DIN)
unnamed: D181.4 (DOUT), D182.2 (DIN)
unnamed: D182.4 (DOUT), D183.2 (DIN)
unnamed: D183.4 (DOUT), D184.2 (DIN)
unnamed: D184.4 (DOUT), D185.2 (DIN)
unnamed: D185.4 (DOUT), D186.2 (DIN)
unnamed: D186.4 (DOUT), D187.2 (DIN)
unnamed: D187.4 (DOUT), D188.2 (DIN)
unnamed: D188.4 (DOUT), D189.2 (DIN)
unnamed: D189.4 (DOUT), D190.2 (DIN)
unnamed: D190.4 (DOUT), D191.2 (DIN)
unnamed: D191.4 (DOUT), D192.2 (DIN)
unnamed: D192.4 (DOUT), D193.2 (DIN)
unnamed: D193.4 (DOUT), D194.2 (DIN)
unnamed: D194.4 (DOUT), D195.2 (DIN)
unnamed: D195.4 (DOUT), D196.2 (DIN)
unnamed: D196.4 (DOUT), D197.2 (DIN)
unnamed: D197.4 (DOUT), D198.2 (DIN)
unnamed: D198.4 (DOUT), D199.2 (DIN)
unnamed: D199.4 (DOUT), D200.2 (DIN)
unnamed: D200.4 (DOUT), D201.2 (DIN)
unnamed: D201.4 (DOUT), D202.2 (DIN)
unnamed: D202.4 (DOUT), D203.2 (DIN)
unnamed: D203.4 (DOUT), D204.2 (DIN)
unnamed: D204.4 (DOUT), D205.2 (DIN)
unnamed: D205.4 (DOUT), D206.2 (DIN)
unnamed: D206.4 (DOUT), D207.2 (DIN)
unnamed: D207.4 (DOUT), D208.2 (DIN)
unnamed: D208.4 (DOUT), TP3.1
unnamed: J0.A5 (CC1), R10.1
unnamed: J0.B5 (CC2), R0.1
unnamed: Q0.1 (B), R1.2
unnamed: Q0.2 (E), R2.1, U0.14 (~RTS)
unnamed: Q1.1 (B), R2.2
unnamed: Q1.2 (E), R1.1, U0.13 (~DTR)
unnamed: C47.2, Q2.1 (G), R9.1
unnamed: R5.1, U0.3 (RXD)
unnamed: R4.1, U0.2 (TXD)
unnamed: J0.A6 (D+), J0.B6 (D+), U0.5 (UD+)
unnamed: J0.A7 (D-), J0.B7 (D-), U0.6 (UD-)
unnamed: C0.2, U0.4 (V3)
unnamed: R3.2, U2.3 (EN)
unnamed: R7.1, U2.17 (GPIO2)
unnamed: R6.1, U2.16 (GPIO15)
unnamed: R8.1, U3.4 (B)
VBUS: C1.2, C47.1, J0.A4 (VBUS), J0.A9 (VBUS), J0.B4 (VBUS), J0.B9 (VBUS), Q2.3 (S)

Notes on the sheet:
All On: 42.61ma * 207 = 8.82A (not realistic, never would have all white) Green: 14.08ma Red: 14.71ma * 207 = 3.04A (not realistic, never would be all full brightness and on) Blue: 14.28ma All Off: 0.5ma
Jannett W

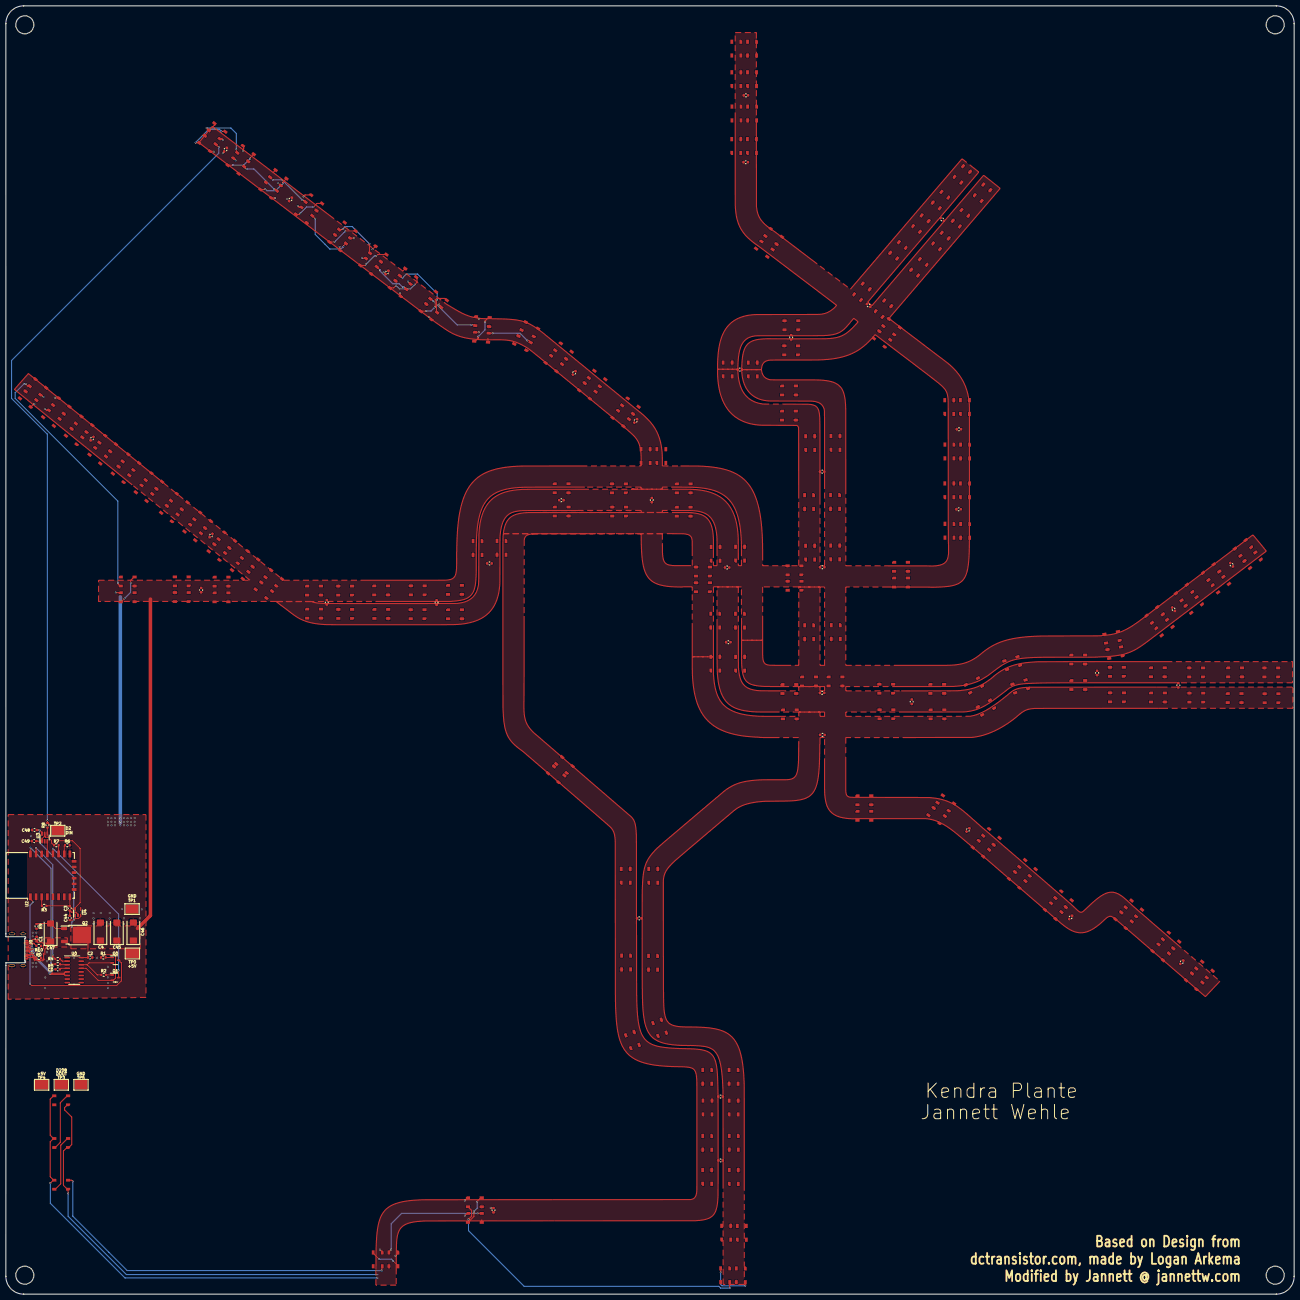
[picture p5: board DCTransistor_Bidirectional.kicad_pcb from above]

Board: 2 copper layers, 457.2 x 457.2 mm, 286 parts (0 on the bottom side), 233 nets.

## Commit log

2025-01-25 schematic changes
    [DCTransistor_Bidirectional.kicad_sch]
2025-02-03 removed graphic temporarily for layout
    [DCTransistor_standard.kicad_sch, DCTransistor_standard_BOM.xlsx]
2025-02-08 recentered pcb
2025-02-09 layout and footprint changes
    [DCTransistor_Bidirectional.kicad_sch]
2025-03-16 layout fixes and schematic re-sync with layout
    [DCTransistor_Bidirectional.kicad_pcb, DCTransistor_Bidirectional.kicad_sch]
2025-03-16 layout updates
    [DCTransistor_Bidirectional.kicad_pcb, DCTransistor_Bidirectional.kicad_sch]
